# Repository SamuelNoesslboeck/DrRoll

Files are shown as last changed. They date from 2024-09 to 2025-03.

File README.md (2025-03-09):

<p align="center">
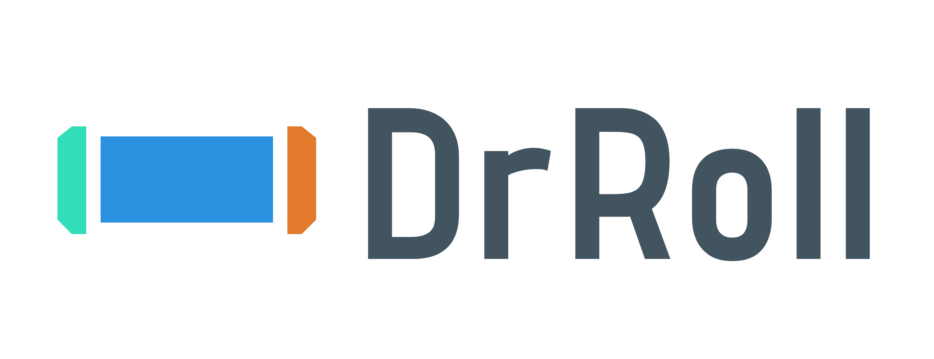
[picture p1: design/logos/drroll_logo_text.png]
  
</p>

---

A mobile storage for technical drawings!

## Idea / Concept

As larger paper like A2 and above require either folding, rolling or other ways to be transported in a meaningful way and I personally dislike folding any paper for purposes other than origami (which I actually love), I took one of the cardboard rolls where you usually keep stuff like posters in and used it for my technical drawings.

## Final design & build

The final CAD design, created in Solid Edge, is available in the root of the repo. Below is a capture of the assembly and a snapshot of the [assembly drawing](export/a_drroll.pdf):

<p align="center">
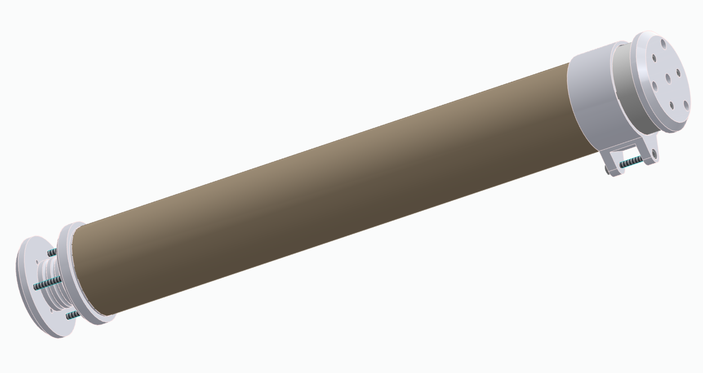
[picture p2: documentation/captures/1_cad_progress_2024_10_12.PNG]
  
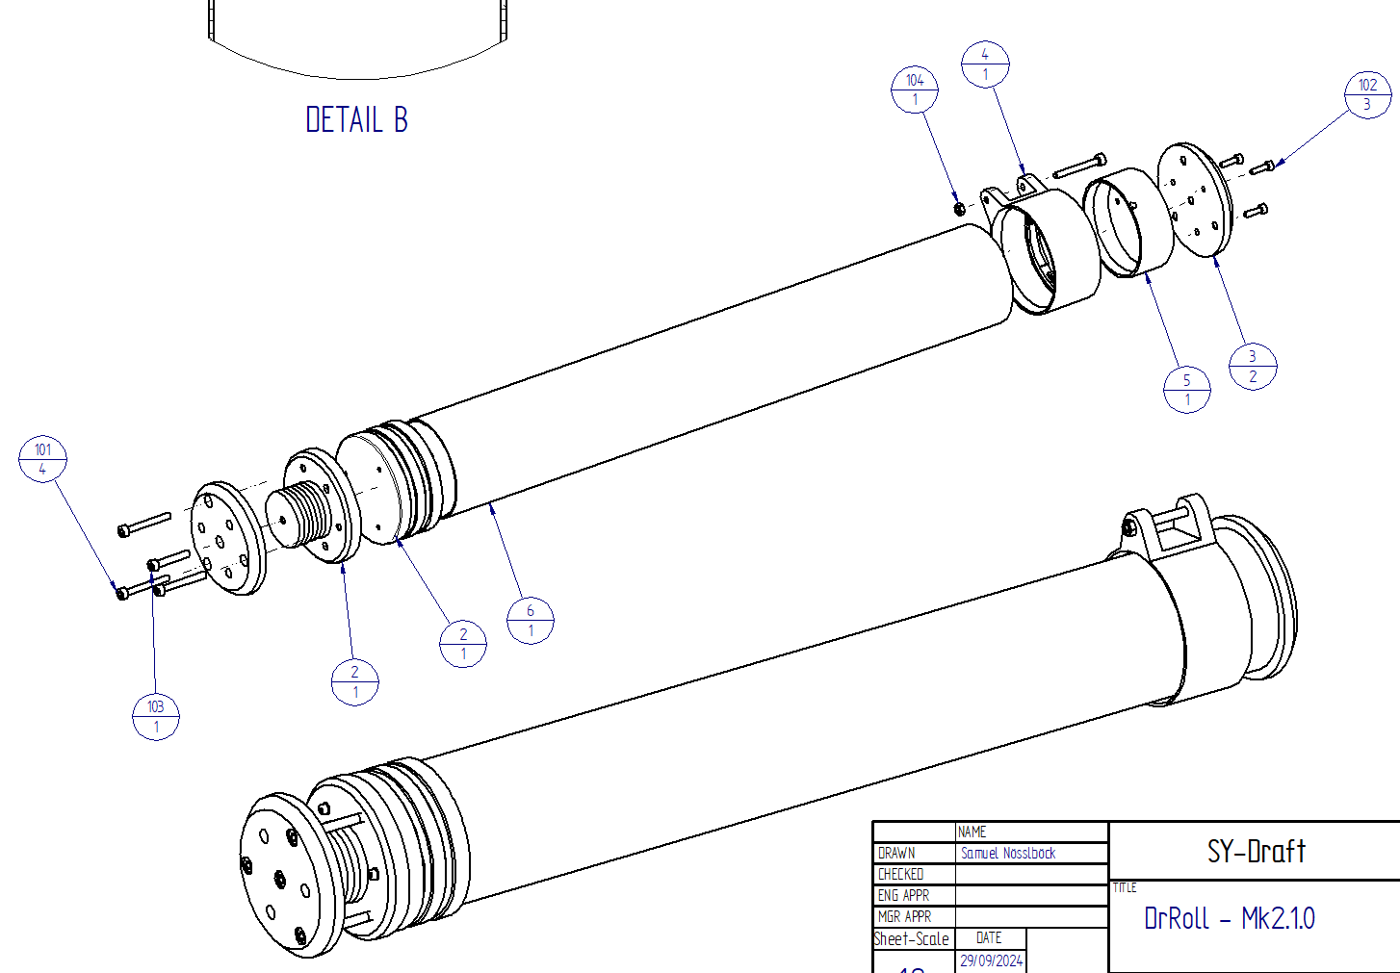
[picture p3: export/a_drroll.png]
  
</p>

more images of the real life build can be found in the project log and a lot of concept art is available in the [project log](documentation/project_log.md)!

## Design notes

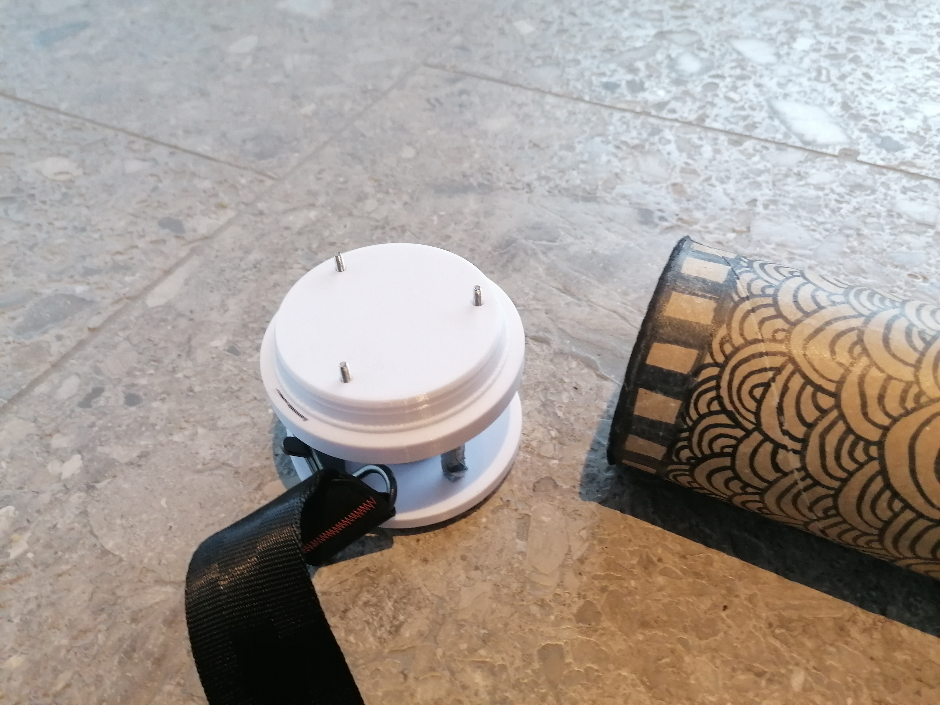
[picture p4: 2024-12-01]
documentation/pictures/11_broken_end_screws.jpg

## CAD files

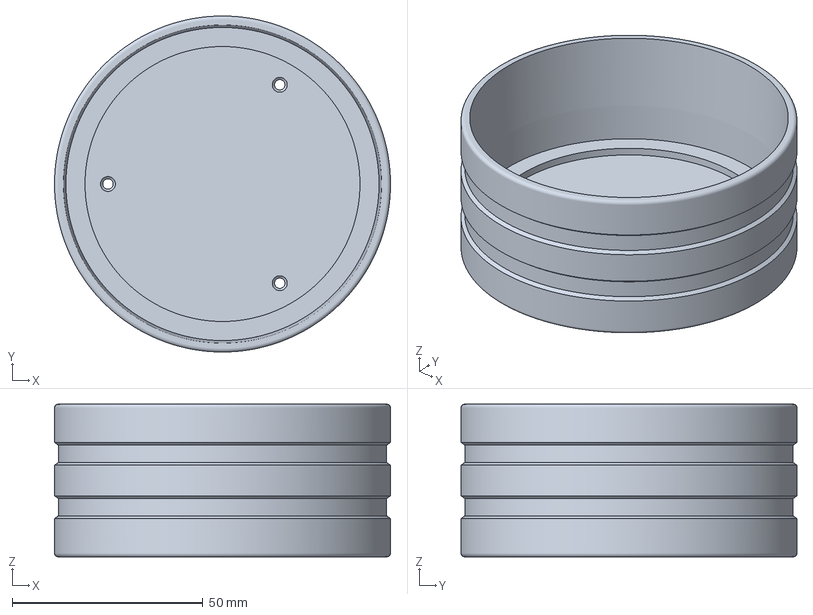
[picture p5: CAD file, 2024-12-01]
slicer/1_bottom_roll_cap.3mf
88.0 x 88.0 x 40.0 mm

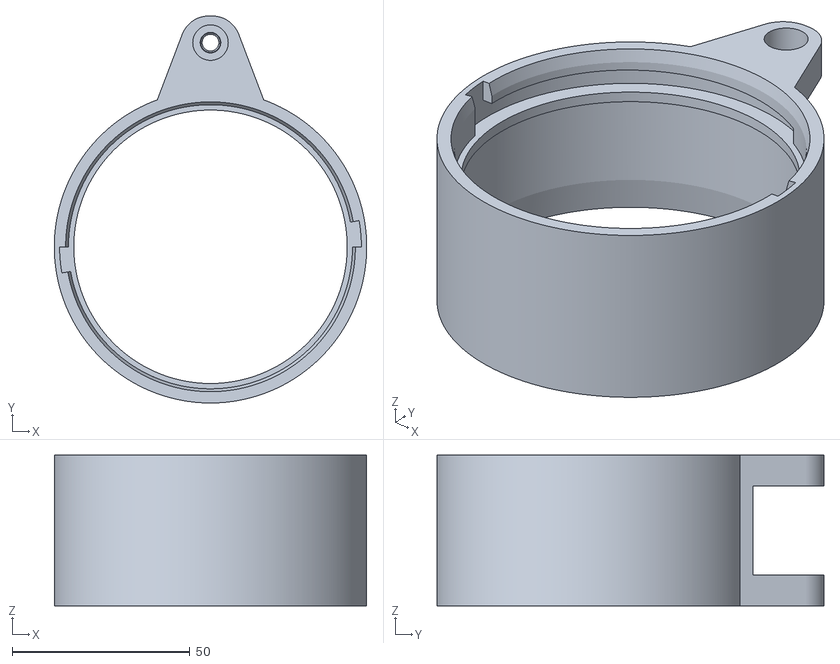
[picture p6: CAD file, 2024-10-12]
stl/4_top_body.stl
88.0 x 109.0 x 42.5

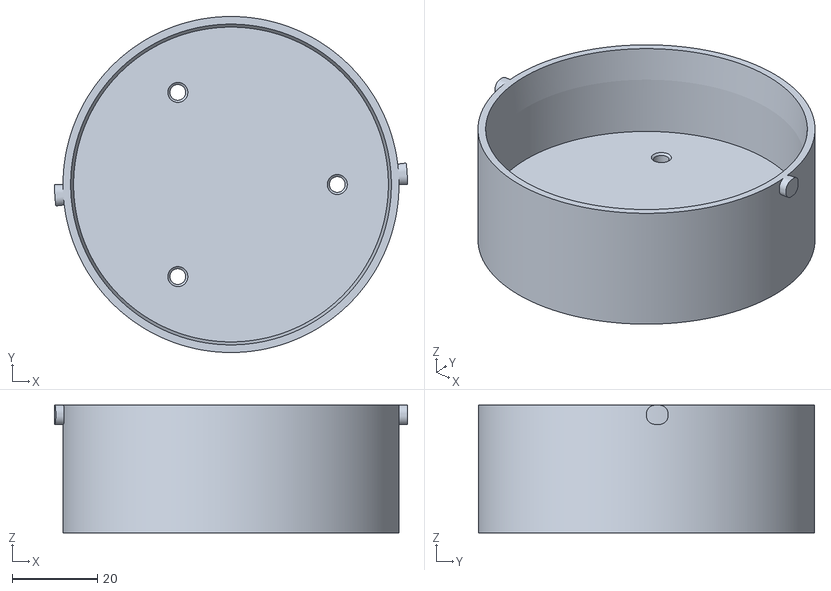
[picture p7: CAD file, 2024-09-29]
stl/5_top_hull.stl
83.0 x 79.0 x 30.0

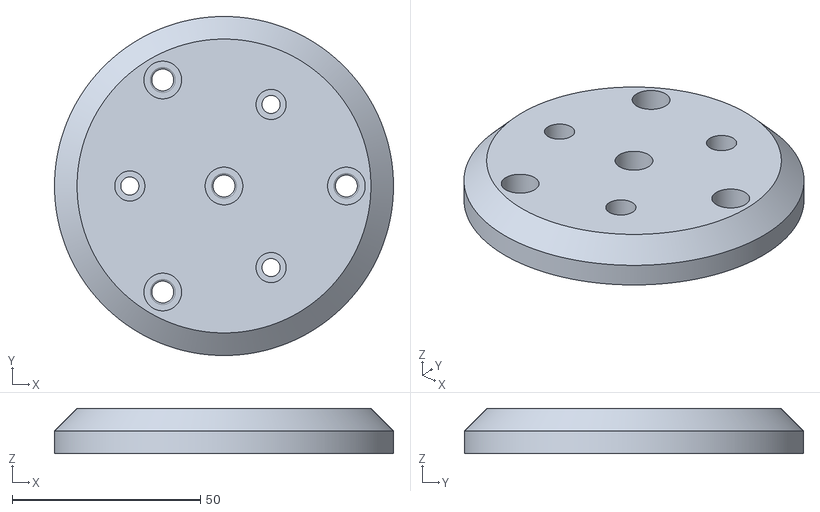
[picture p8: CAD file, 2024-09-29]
stl/3_cap.stl
90.0 x 90.0 x 12.0

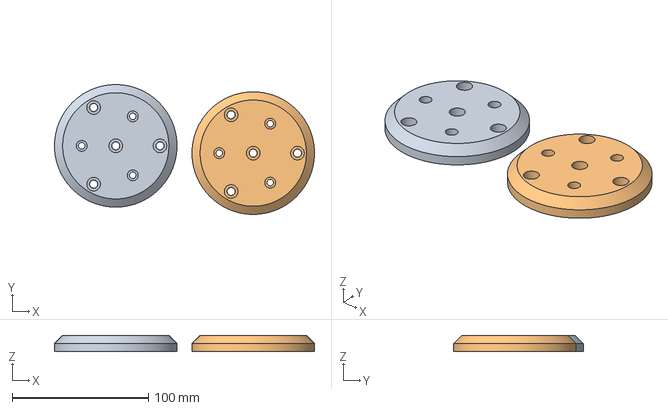
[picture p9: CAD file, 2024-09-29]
slicer/3_cap.3mf
191.0 x 95.4 x 12.0 mm
3_cap.stl x 2

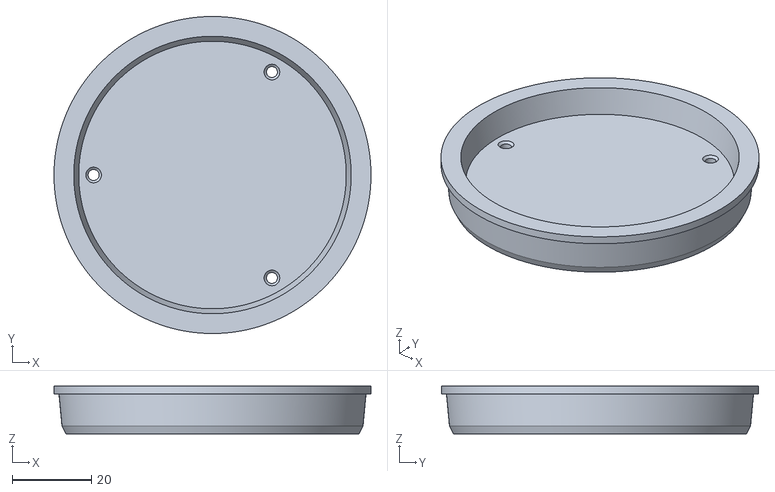
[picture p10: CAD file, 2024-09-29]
stl/1_bottom_roll_cap.stl
80.0 x 80.0 x 12.0

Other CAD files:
slicer/4_top_body.3mf
slicer/5_top_hull.3mf

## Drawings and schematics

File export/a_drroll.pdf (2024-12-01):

A

B

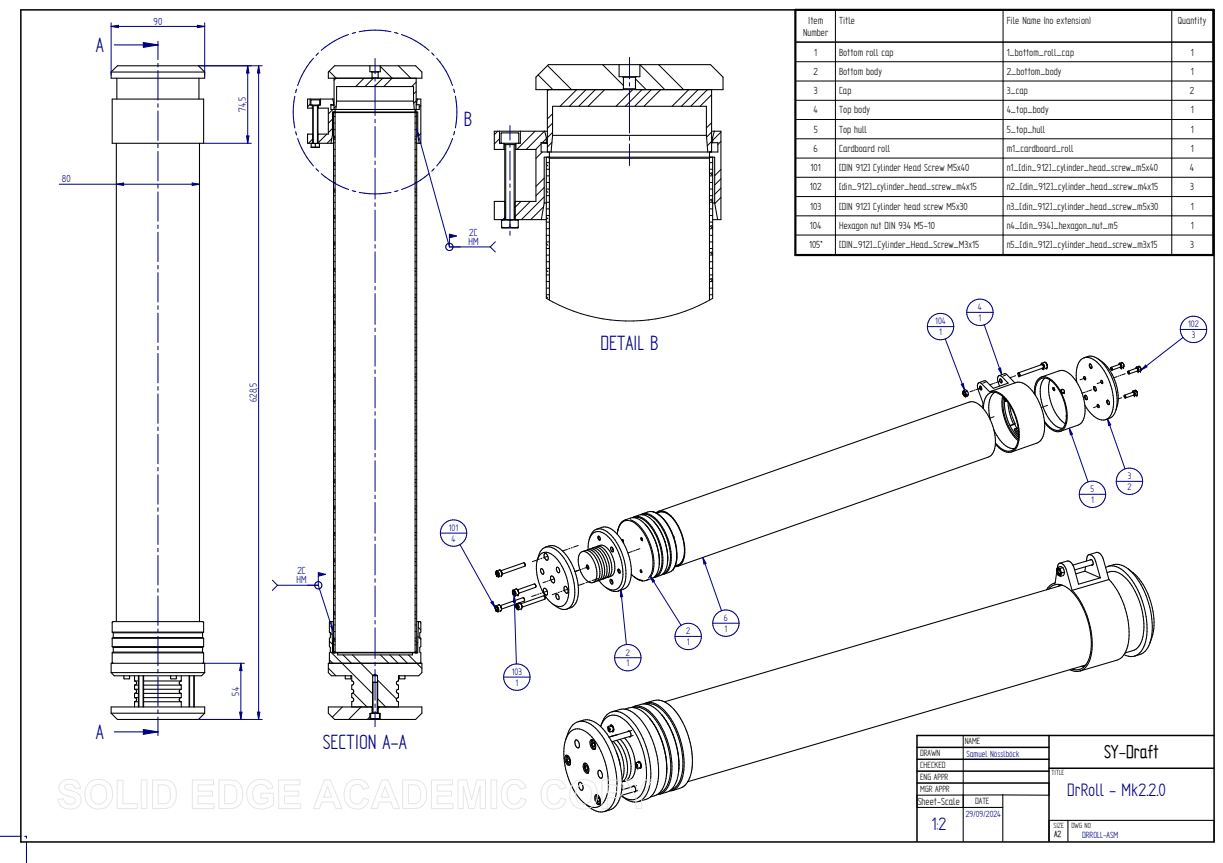
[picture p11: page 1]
TITLE; DrRoll - Mk2.2.0; SECTION A-A; DETAIL B; Item Number; Title; File Name (no extension); Quantity

1 | Bottom roll cap | 1_bottom_roll_cap | 1
2 | Bottom body | 2_bottom_body | 1
3 | Cap | 3_cap | 2
4 | Top body | 4_top_body | 1
5 | Top hull | 5_top_hull | 1
6 | Cardboard roll | m1_cardboard_roll | 1
101 | [DIN 912] Cylinder Head Screw M5x40 | n1_[din_912]_cylinder_head_screw_m5x40 | 4
102 | [din_912]_cylinder_head_screw_m4x15 | n2_[din_912]_cylinder_head_screw_m4x15 | 3
103 | [DIN 912] Cylinder head screw M5x30 | n3_[din_912]_cylinder_head_screw_m5x30 | 1
104 | Hexagon nut DIN 934 M5-10 | n4_[din_934]_hexagon_nut_m5 | 1
105* | [DIN_912]_Cylinder_Head_Screw_M3x15 | n5_[din_912]_cylinder_head_screw_m3x15 | 3

NAME | SY-Draft

DRAWN | Samuel Nösslböck
CHECKED
ENG APPR
MGR APPR
Sheet-Scale | DATE
1:2 | 29/09/2024

SIZE A2 | DWG NO DRROLL-ASM

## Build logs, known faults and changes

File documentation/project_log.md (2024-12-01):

# Project Log

## Project cause

I always loved drawing on these large A1 & A2 sheets and making huge technical drawings, with quite the detail, on them. However I hated folding them and it made clean drawing on these sheets hard on the folded edges. I also personally don't like the look of it. 

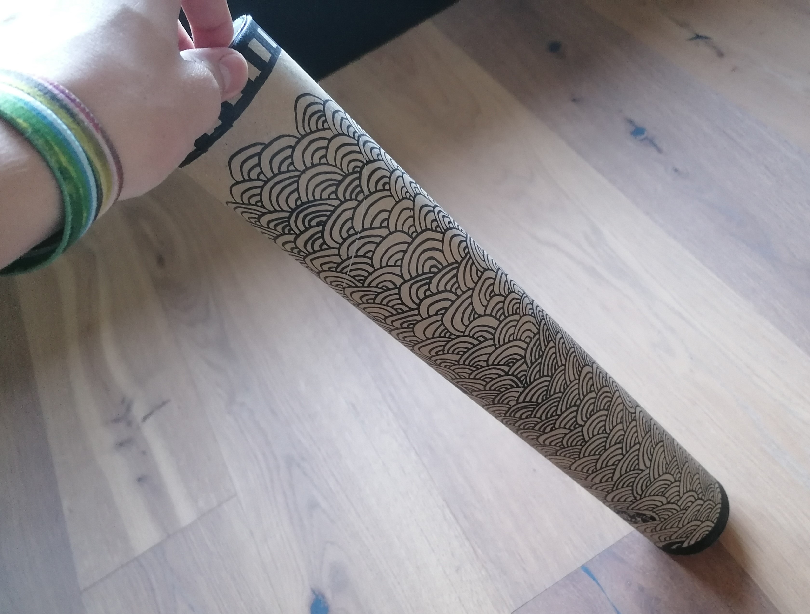
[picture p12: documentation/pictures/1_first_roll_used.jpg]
Cardboard roll with fancy pattern


Soon I came across one of those cardboard rolls, that you usually transfer posters and similar in, and it quickly became quite handy for this purpose of transporting my drawings. First I used to tie the roll to my backpack using some strings and ropes. But as these cardboard rolls are not designed for longer term use, especially the caps, and they have no handles or attachments for belts and similar, I soon needed some custom attachments to the roll.

## First attachments and own project - Mk1 (abt. 2022/06)

Sadly I barely have any files left of the first roll and reasons why I made some design choices, however I have this image:

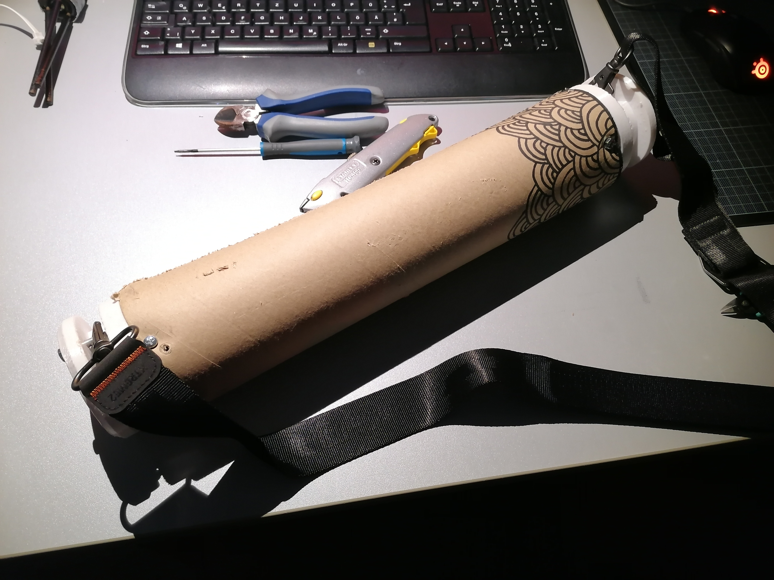
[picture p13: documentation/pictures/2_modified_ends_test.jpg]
Mk1 build in progress


For this build, I used a new cardboard roll and tried to design my own caps with some connectors to them. Sadly this design was absolute trash, there was little to no possibility to open the roll in a clean why, so I discarded this design very quickly.

## Concept for Mk2

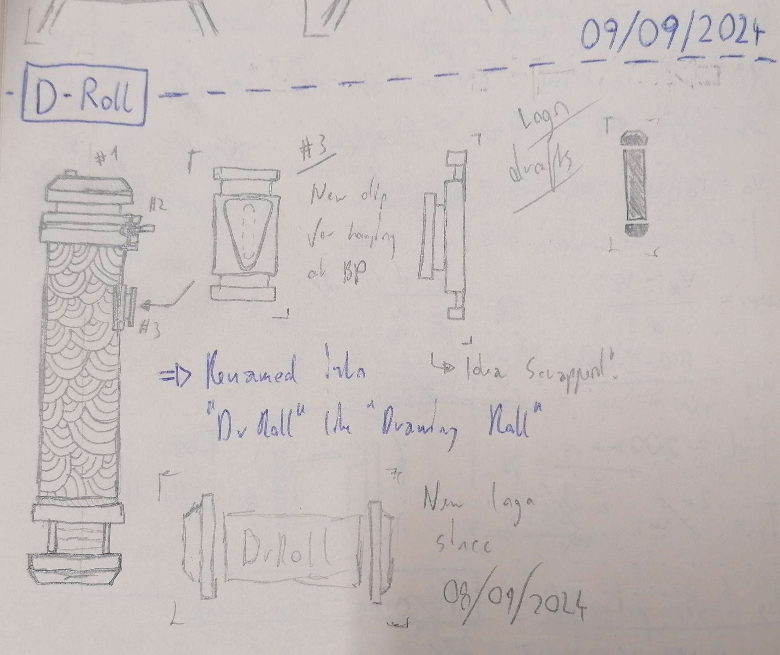
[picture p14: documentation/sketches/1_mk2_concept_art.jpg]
Mk2 concept art


The new Mk2 build should have a fixed bottom end with multiple screws and possible mounting options. However the top part should have something like a little hook on the side to mount the belt too, while also functioning as a seal.

## First build of Mk2 (Mk2.0.0)

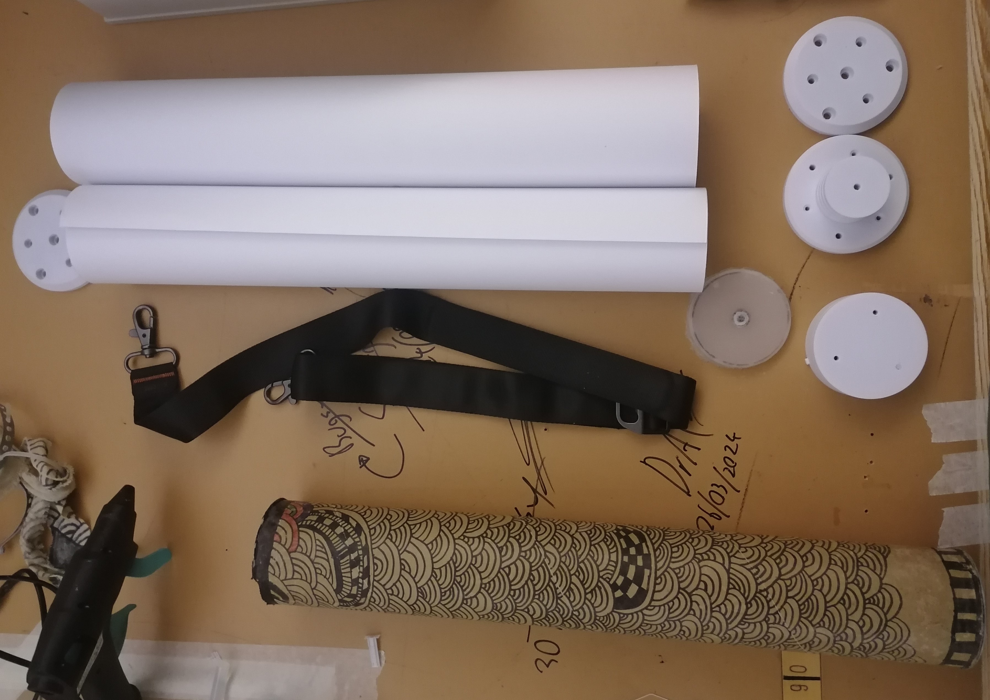
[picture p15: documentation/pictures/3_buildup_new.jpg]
Mk2 build-up


The first build was finished on the 30/09/2024 and was directly put to use when I was travelling to Switzerland. The following things came up while or after traveling:

- The top part is not fully centred, as the roll appears to be larger than planned, probably because it was stretched over time by the cap used
- The new bottom part is not only extremely useful, but also very, very stable. It is likely that there are no further changes to be made to this part of the roll

The issues with the top part caused wrapping, which made using the roll basically impossible:

<p align="middle">
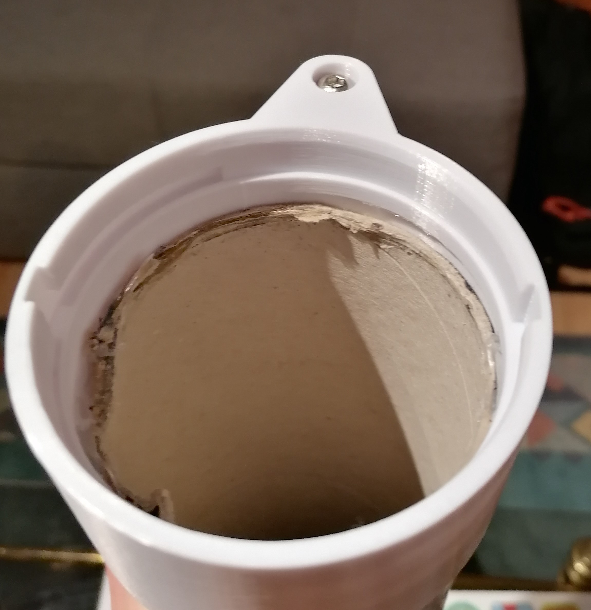
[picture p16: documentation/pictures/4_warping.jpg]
    
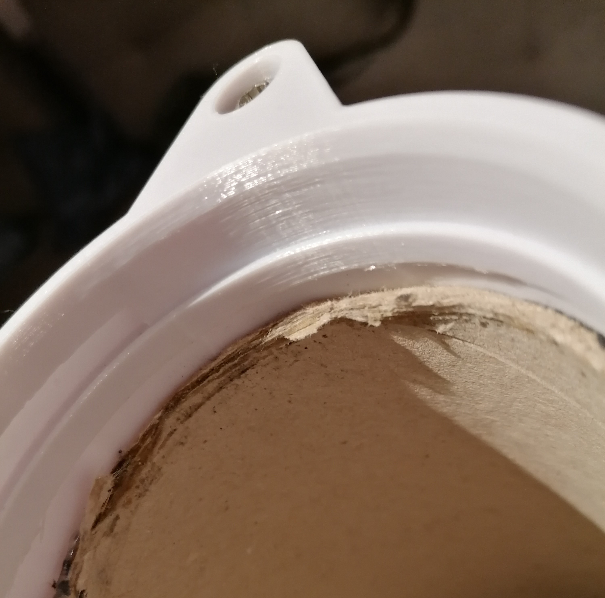
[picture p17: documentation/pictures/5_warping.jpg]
    
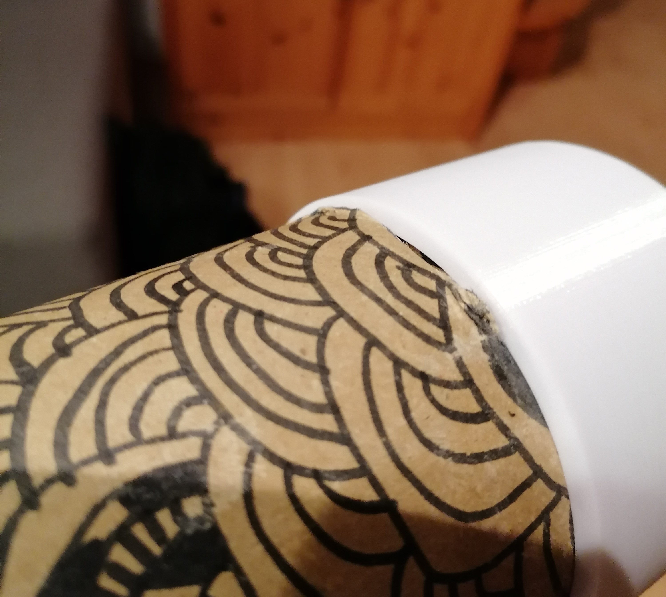
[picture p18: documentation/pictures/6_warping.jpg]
    
</p>

## Fixed version (Mk2.1.0)

With Mk2.1.0 I was able to remove all of the issues listed in Mk2.1.0, hopefully no new ones will emerge for now. Here a very low quality picture of the result (it was a quick picture for my best friend please excuse haha):

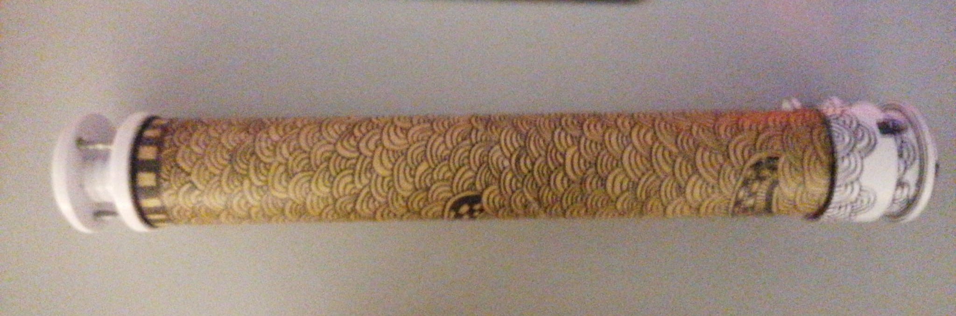
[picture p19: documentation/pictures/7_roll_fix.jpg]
Mk2.1.0 build


## Durability problems in winter (Mk2.2.0)

Now two months into use, the DrRoll is showing the first signs of longer-term usage. With the colder temperatures and higher moisture conditions, the 3D-printed parts seem to deform in a way, causing the glue between the cardboard to lose it's strength. This inevitably led to the bottom part, the one with less area where glue is spread on, broke free from the cardboard roll. 

<p align="middle">
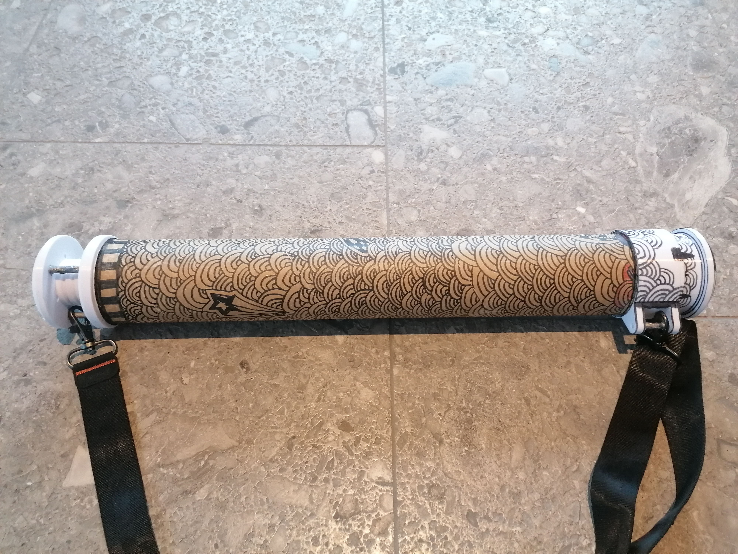
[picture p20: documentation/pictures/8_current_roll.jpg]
    
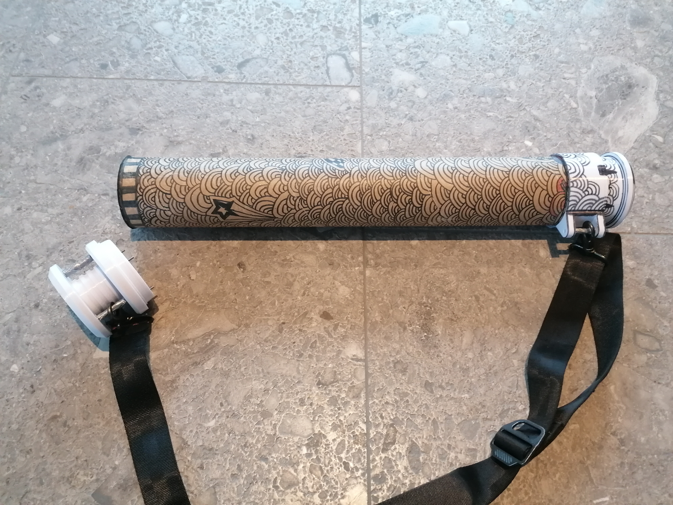
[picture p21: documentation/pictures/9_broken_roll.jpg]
    
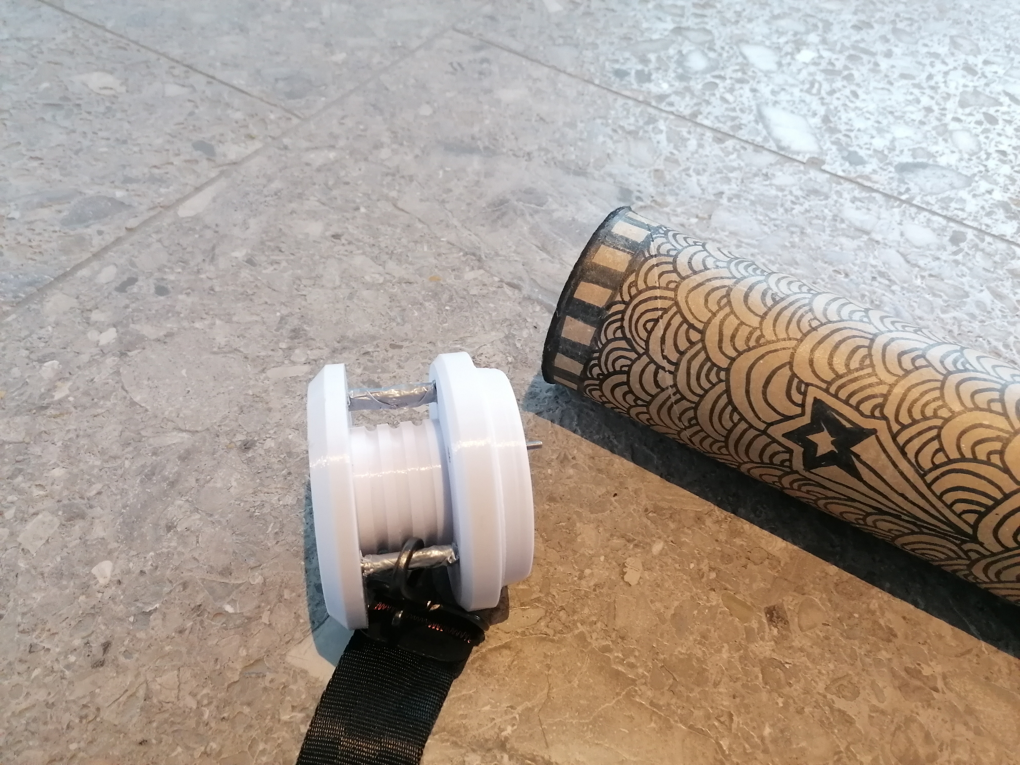
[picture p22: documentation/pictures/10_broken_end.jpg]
    
</p>

Additionally, the old cap did not only have little connection-area to the cardboard roll, it also had little space for the screws to be put though. So for the next version, I took the upper connection part as a reference and increased the thread length to properly fit the screws in. The new roll bottom looks like the following:

<p align="middle">
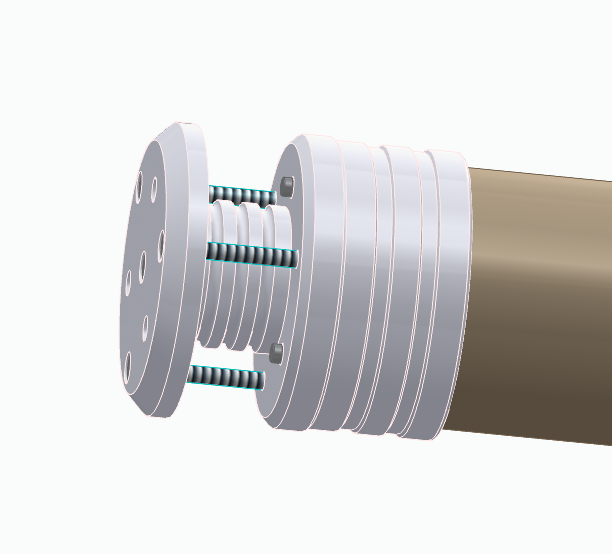
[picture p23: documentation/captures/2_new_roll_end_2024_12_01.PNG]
    
    
</p>

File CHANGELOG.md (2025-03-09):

# DrRoll - Changelog

> For a more detailed history of actions taken see the [project log](./documentation/project_log.md)

## Mk2.1.0/2024/10/12

- Improved the seal, ensuring a tighter closing
- Re-dimensioned the top parts to better fit the roll, causing no wrapping anymore

## Mk2.2.0/2024/12/01 

- Reworked the bottom part of the roll for a better connection in order to withstand environmental conditions better
- Improved technical drawing to include adhesive dimensions

## Mk2.2.1/2025/03/09

- Added new logos and designs

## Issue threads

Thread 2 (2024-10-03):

Add tape to screws to remove the noise created by the belt

SamuelNoesslboeck, 2024-10-03:

Closed 2024-10-25.

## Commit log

2024-09-25 init commit
    [a_drroll.cfg]
2024-09-29 cad progress
    [1_bottom_roll_cap.3mf, 1_bottom_roll_cap.stl, 3_cap.3mf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]
2024-10-11 further cad changes
    [4_top_body.3mf, 4_top_body.stl, a_drroll.cfg]
2024-12-01 fixing and documenting issue of broken roll
    [a_drroll.cfg]
